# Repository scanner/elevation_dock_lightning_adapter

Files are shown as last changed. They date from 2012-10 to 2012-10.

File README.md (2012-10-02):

elevation_dock_lightning_adapter
================================

Plastic insert for the ElevationLabs Elevation Dock to use an Apple Lightning cable instead of the 30 pin dock adapter it comes with.

This is orginally based on the thing http://www.thingiverse.com/thing:31429 but the calibration between whatever was made to print that and my replicator is off. The lighting cable would not even fit in to the rectangular hole they used.

So I took their idea and made my own version. Since the tolerances are pretty tight on this and every printer is slightly different at those tolerances you may need to tweak the OpenSCAD file to produce a STL that is useable. But hey, that is why this is all up on thingiverse.

I used the lightning adapter cutout from another one of my designs for this. This means that it is pretty much flush with the top of the plug, and it has a bottom so that you can not (easily at least) push it out by docking your iPhone.

Also the friction fit of the bottom plate was not as good as I wanted and repeated dockings would slowly push it out so I decided to use the two holes provided so you could screw this into the elevation dock and not have it go anywhere.

I use two M3 8mm bolts.

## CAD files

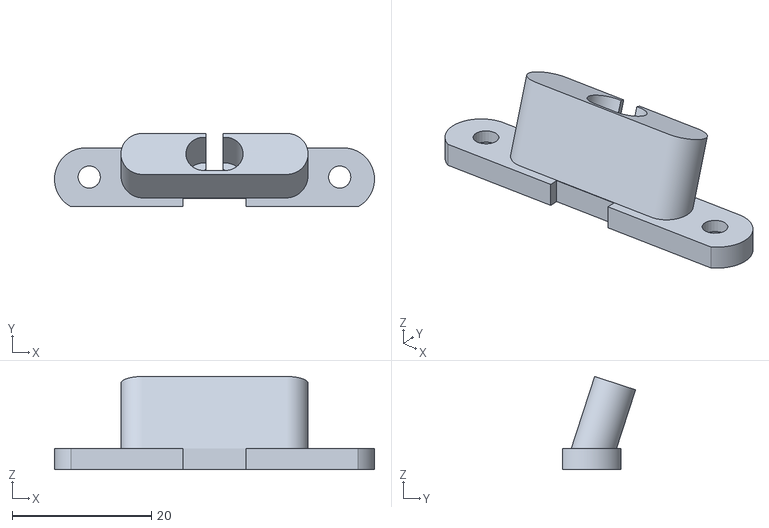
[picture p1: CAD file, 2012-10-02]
elevation_dock_lightning_adapter.stl
46.0 x 10.5 x 13.4

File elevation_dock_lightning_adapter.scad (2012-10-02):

//
// I was not content with the lightning adapter posted to the thingiverse since
// I had come up with what I think of as a better cutout for the lightning
// plug. So I am extending thing xxx with this model instead.
//

use <Libs.scad>;

padding = 0.1;

// Lightning plug dimensions
//
lightning_w = 8.2;
lightning_d = 5;
lightning_h = 12;
lightning_cable_r = 2.5/2;
lightning_strain_relief_r = 4.1/2;


// How much more it leans back from perfectly 90 up
//
plug_angle = -18 ; // -8;

// thickness of the base this is all mounted on
//
base_thickness = 3;
base_width = 46;
base_depth = 9;
bolt_offset = 18;
bolt_r = 3.2/2; // M3 bolt

plug_width = 26.9;
plug_depth = 6.2;
// plug_height = 8.13;
plug_height = lightning_h - 1;

/////////////////////////////////////////////////////////////////////////////
//
module hexagon(r) {
    scale(v = [r, r, 1]) polygon(points=[[1,0],[0.5,sqrt(3)/2],[-0.5,sqrt(3)/2],[-1,0],[-0.5,-sqrt(3)/2],[0.5,-sqrt(3)/2]], paths=[[0,1,2,3,4,5,0]]);
}

////////////////////////////////////////////////////////////////////////
//
// Make a hexagon suitable for differencing out a hex nut.
//
module hex_nut(r, h) {
    linear_extrude(height = h, center = true, convexity = 10, twist = 0) hexagon(r);
}

/////////////////////////////////////////////////////////////////////////////
//
// Like the headphone plug we need a shape sized to the lightning connector
// with a nice tight fit. It is actually oval shaped, but a rounded rectangle
// is good enough since the size is small and we want a tight fit.
//
module lightning_plug() {
    translate( v = [0,0,lightning_h/2] ) {
        roundRect( size = [lightning_w, lightning_d, lightning_h],
            round = lightning_d / 2, center = true);
    }
}

/////////////////////////////////////////////////////////////////////////////
//
// the cut out for the lightning cable.
//
module lightning_cable_cutout(height) {
    translate( v = [0,0,height/2] ) {
        union() {
            cylinder( h = height, r = lightning_strain_relief_r, center = true, $fn = 16 );
            translate( v = [0,-(height/2),0]) {
                cube([lightning_cable_r*2, height, height], true);
            }
        }
    }
}

/////////////////////////////////////////////////////////////////////////////
//
// The base that snaps in to the elevation dock.
//
module elevation_dock_adapter() {
    difference() {
        union() {
            // The base plate
            //
            translate( v = [0,0.4,base_thickness/2]) {
                roundRect( size = [base_width, base_depth, base_thickness], round = base_depth / 2, center = true );
            }
            // The plug
            //
            rotate([plug_angle, 0,0]) {
                translate( v = [0,0, base_thickness] ) {
                    translate( v = [0,0, (plug_height / 2)-1.45]) {
                        roundRect( size = [ plug_width, plug_depth, plug_height + 1 ],
                            round = plug_depth / 2, center = true );
                    }
                }
            }
        }

        // The notch in the base plate.
        //
        translate( v = [0, -5, base_thickness / 2]) {
            cube([9,5.3,base_thickness + 1], true);
        }
        translate( v = [0, -6.2, base_thickness / 2]) {
            cube([base_width,5.3,base_thickness + 1], true);
        }


        // The lightning plug shoots up the middle at the same angle as the
        // plug.
        //
        rotate([plug_angle, 0,0]) {
            translate( v = [0,0,1.1] ) {
                lightning_plug();
            }
        }

        // and we have bolt holes on either side of the base..
        //
        translate( v = [-bolt_offset, 0.7, -padding] ) {
            cylinder( r = bolt_r, h = 10, $fn = 25 );
            hex_nut(3.5, 3);
        }
        translate( v = [bolt_offset, 0.7, -padding] ) {
            cylinder( r = bolt_r, h = 10, $fn = 25 );
            hex_nut(3.5, 3);
        }

        // And a notch cut out of the side for us to run our cable through.
        //
        rotate([plug_angle, 0, 0]) {
            translate( v = [0,4,0]) {
                cube([lightning_cable_r*2, 8, 30], true);
            }
            translate( v = [0,0,-5]) {
                cylinder(h=10,r=lightning_strain_relief_r, $fn = 25);
            }
        }
    }
}

// lightning_plug();
elevation_dock_adapter();

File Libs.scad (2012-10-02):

/*   	MY Libraries v1.1 - Common Components
		Unless stated otherwise, all modules
		are by Randy Young <dadick83@hotmail.com>
		2010, 2011.   License, GPL v2 or later
**************************************************/

displayMode= rezScreen();  // (resolution)

function rezPrinter()=0;
function rezScreen()=1;

function resolution(value) =
	displayMode==1 ? 360 : value*2*3.141592; // ~1mm resolution for printer
$fn=resolution(4); // default for cylinder & sphere

function vectorDistance(v1, v2) =
	sqrt((pow(v2[0]-v1[0],2)+pow(v2[1]-v1[1],2))+pow(v2[2]-v1[2],2));
// function for linear measurement from 2, 3d vectors)

ep=0.01; //small number to avoid overlaps (non-manifold models)
in=25.4; //inches to millimeter conversion


/***** ROTATION & TRANSLATION SHORTCUTS  *****
Used for common, easy to type single axis moves 
with names I can actually remember (since I never
get the rotation directions right on first try. :o)   */

function tighten (angle=90) =
		[0,0,-1*angle];

function loosen (angle=90) =
		[0,0,angle];

function righty (angle=90) =
		[0,angle,0];

function lefty (angle=90) =
		[0,-1*angle,0];

function backward (angle=90) =
		[-1*angle,0,0];

function forward (angle=90) =
		[angle,0,0];

function push(distance=1) =
		[0,distance,0]; 

function lift(distance=1) =
		[0,0,distance];

function slide(distance=1) =
		[distance,0,0]; 

/*************************************************
BASIC ENGINEERING SHAPES */

module hex (width=10, height=10, flats= true, center=false){
	radius= (flats == true ? width/sin(60)/2 : width/2 );
		cylinder (r=radius, h=height, center=center, $fn=6);
}

module equilateralTriangle (side=10, height=10, center=false){
	translate(center==true ? [-side/2,-sqrt(3)*side/6,-height/2] : [0,0,0])	
		linear_extrude(height=height)
			polygon(points=[[0,0],[side,0],[side/2,sqrt(3)*side/2]]);
}

module pyramid(side=10, height=-1, square=false, centerHorizontal=true, centerVertical=false){
// creates a 3 or 4 sided pyramid.  -1 height= tetrahedron or Johnson's Solid square pyramid
	mHeight= height!=-1 ? height:
		square == true ? (1/sqrt(2))*side:		//square
			sqrt(6)/3*side;						//tetra
	vert= centerVertical!=true ? [0,0,0]:
		square==false ? [0,0,-mHeight/4] :	 //inscribes a tetra inside a sphere, not 1/2 ht
			[0,0,-mHeight/2];	//for squares, center=false inscribes, so true is just 1/2 ht
	horiz= centerHorizontal!= true ? [0,0,0] :
		square == true ? [-side/2, -side/2, 0] : 	//square
			[-side/2,-sqrt(3)*side/6 ,0];			//tetra
	translate(vert+horiz){
		if (square == true){
			polyhedron (	points = [[0,0,0],[0,side,0],[side,side,0],
								[side,0,0],[side/2,side/2,mHeight]], 
						triangles = [[1,0,2], [2,0,3], [0,4,3], 
								[3,4,2], [2,4,1], [1,4,0]]);
		}
		if (square != true){
			polyhedron (	points = [[0,0,0],[side,0,0],[side/2,sqrt(3)*side/2,0],
								[side/2,sqrt(3)*side/6,mHeight]], 
						triangles = [[0,1,2], [1,0,3], [2,1,3],[2,3,0]]);			
		}
}	}

module tube(r=2, thickness=1, height=1, center=false, outline=false){
	translate(lift(center == true ?  0 : 0.5*height)) 
	difference(){
		cylinder(r=r, h=height, center=true, $fn=resolution(r));
		if (outline!=true)
			cylinder(r=r-thickness+ep, h=height+2*ep, center=true, $fn=resolution(r-thickness));
}	}

module roundRect (size=[10,10,10], round=3, center=false){
	$fn=resolution(round);
	radius = min(round, size[0]/2, size[1]/2);
	union(){
		translate(center==true ? [-size[0]/2,-size[1]/2,-size[2]/2] : [0,0,0]){
			translate([radius,radius,0])
				cylinder (r=radius, h=size[2]);
			translate([size[0]-radius,radius,0])
				cylinder (r=radius, h=size[2]);
			translate([size[0]-radius,size[1]-radius,0])
				cylinder (r=radius, h=size[2]);
			translate([radius,size[1]-radius,0])
				cylinder (r=radius, h=size[2]);
			translate([0,radius,0]) 
				cube(size-[0,radius*2,0]);
			translate([radius,0,0]) 
				cube(size-[radius*2,0,0]);
}	}	}

module keyhole(r1, r2, length, height) {
	translate ([0,length/2,0]) union(){
		translate ([0,length/2-r1,0]) 
			cylinder (r=r1, height, $fn=resolution(r1));
		translate ([0,0-(length/2-r2),0]) 
			cylinder (r=r2, height, $fn=resolution(r2));
		translate ([-r1,r1-length/2,0]) 
			cube ([r1*2,length-(r1*2),height]);
	}
}

module slot(size=[4,10,1], startRound=true, endRound=true, centerXYZ=[1,0,0]){
	$fn=resolution(size[0]/2);
	radius=size[0]/2;
	start= startRound==true ? radius : 0;
	end= endRound==true ? radius : 0;
	translate([-size[0]/2*centerXYZ[0],
			-size[1]/2*centerXYZ[1],
			-size[2]/2*centerXYZ[2]]) 
	union(){
		translate([0,start,0]) cube (size-[0,start+end,0]);
		if (startRound==true) translate ([radius,radius,0])
			cylinder (r=size[0]/2, h=size[2]);
		if (endRound==true) translate ([radius,size[1]-radius,0])
			cylinder (r=size[0]/2, h=size[2]);
	
}	}

module dovetail (width=9, height=10, male=true){
	w= (male==true) ? width*0.975 : width;
	translate(slide(2.4)) union(){
		rotate(tighten(30))
			equilateralTriangle(w,height, center=true);
		translate(slide(-4.5)) cube([4.2,width*1.5,height], center=true);}
}

module teardrop(radius=5, length=10, angle=90) {
// teardrop module by whosawhatsis <www.thingiverse.com/thing:3457>
// Creative Commons LGPL, 2010.  I added default values and resolution code
	$fn=resolution(radius);
	rotate([0, angle, 0]) union() {
		linear_extrude(height = length, center = true, convexity = radius, twist = 0)
			circle(r = radius, center = true);
		linear_extrude(height = length, center = true, convexity = radius, twist = 0)
			projection(cut = false) rotate([0, -angle, 0]) 
			translate([0, 0, radius * sin(45) * 1.5]) 
			cylinder(h = radius * sin(45), r1 = radius * sin(45), r2 = 0, 
					center = true);
	}
}


/*************************************************
HARDWARE COMPONENTS */

module hexNut(size="M3", center=false, outline=false, pos=[0,0,0]){
	if (tableRow(size) == -1)	echo(str("hexNut ERROR: size of '",size,"' is undefined."));
	width = tableEntry (size, "nutWidth");
	height = tableEntry (size, "nutThickness");
	hole = tableEntry (size, "nutID");
	translate(pos+lift(center == true ?  0 : 0.5*height)) difference(){
		hex(width, height, center=true);
		if (outline!=true)
			cylinder(r=hole/2+0.01, h=height+0.02, center=true, $fn=resolution(hole/2));
}	}

module washer(size="M3", center=false, outline=false, pos=[0,0,0]){
	if (tableRow(size) == -1)	echo(str("washer ERROR: size of '",size,"' is undefined."));
	width = tableEntry (size, "washerOD");
	height = tableEntry (size, "washerThickness");
	hole = tableEntry (size, "washerID");
	translate(pos) tube(width/2,(width-hole)/2,height,center,outline);
}

module capBolt (size="M3", length= 16, center=false, pos=[0,0,0])	{
	if (tableRow(size) == -1)	echo(str("capBolt ERROR: size of '",size,"' is undefined."));
	diameter = tableEntry (size, "headDiameter");
	head = tableEntry (size, "headThickness");
	stud = tableEntry (size, "studDiameter");	
	translate(pos+[0,0,center == true ? -length/2 : 0]) union()	{
		translate(lift(-head)){
			cylinder(r=diameter/2, h=head, $fn=resolution(diameter/2));
			cylinder(r=stud/2, h=length+head, $fn=resolution(stud/2));
}	}	}

module hexBolt (size="M3", length= 16, center=false, pos=[0,0,0])	{
	if (tableRow(size) == -1)	echo(str("hexBolt ERROR: size of '",size,"' is undefined."));
	width = tableEntry (size, "headDiameter");
	head = tableEntry (size, "headThickness");
	stud = tableEntry (size, "studDiameter");	
	translate(pos+[0,0,center == true ? -length/2 : 0]) union()	{
		translate(lift(-head)){
			hex(width, head, $fn=6);
			cylinder(r=stud/2, h=length+head, $fn=resolution(stud/2));
}	}	}

module bearing (size="Skate", center=false, outline=false, pos=[0,0,0]){
// The Elmom MCAD has a much better version of a bearing module.  
// This is a basic donut shape but gets the job done for construction.
	if (tableRow(size) == -1)	echo(str("bearing ERROR: type of '",type,"' is undefined."));
	hole = tableEntry (size, "bearingID");
	thickness = tableEntry (size, "bearingThickness");
	diameter = tableEntry (size, "bearingOD");
	translate(pos) 
		tube(diameter/2, (diameter-hole)/2, thickness, center, outline);
}
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

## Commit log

2012-10-02 Initial version.
    [Libs.scad, elevation_dock_lightning_adapter.scad, elevation_dock_lightning_adapter.stl]
2012-10-02 Round the base plate tabs. Make the lightning connector cutout have a bottom so you can not push it out.. and cut out a cable run through the side of the connector.
    [elevation_dock_lightning_adapter.scad]
2012-10-02 Make the base thicker by 1mm allowing us to sink the plug stand further in to the base so it does not stick out as much.
    [elevation_dock_lightning_adapter.scad]
2012-10-02 Add M3 hex nut captures to the bottom of the base. Screwing those without the capture is too annoying in that small space.
    [elevation_dock_lightning_adapter.scad]
2012-10-02 Make the notch a bit bigger. Make the hex nut captures a teeny bit bigger too.
    [elevation_dock_lightning_adapter.scad]
2012-10-02 move the holes for the mounting bolts a teeny bit to better align with the mounting holes in the dock. Make the angle of the plug be 15 degrees because the iphone is so thin (and the lightning adapte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
    [elevation_dock_lightning_adapter.scad]
2012-10-02 Need more angle! also make the plug narrower so it is not fighting with the opening when we have it lean over so much. Make the hex nut captures just a teeny bit bigger again too.
    [elevation_dock_lightning_adapter.scad]
2012-10-02 Okay, making the base plate narrower helps. It still is not angled correctly unless you screw it in.. That pushes the base plate flat which angles the plug at the correct angle so that the iphone5 re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
    [elevation_dock_lightning_adapter.scad, elevation_dock_lightning_adapter.stl]

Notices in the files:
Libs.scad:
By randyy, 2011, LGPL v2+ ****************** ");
